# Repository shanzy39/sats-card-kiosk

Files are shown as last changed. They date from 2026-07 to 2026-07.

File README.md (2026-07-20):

# sats-card-kiosk

**Tap a hotel keycard on a little box. Watch Bitcoin appear.**

`sats-card-kiosk` is a DIY, self-contained Lightning kiosk. You lay a repurposed
MIFARE Classic hotel keycard — one that's been loaded with a Bitcoin Lightning
voucher — onto the reader, and the kiosk automatically reads the voucher, claims
it over the internet, and melts the sats into a wallet. A little OLED screen
narrates the whole thing: `tap a card` → `Reading` → `10 sats / claiming...` →
`SUCCESS! melted!`.

No phone, no app, no computer needed at run time. It's an ESP32 microcontroller,
a $7 NFC reader, and a tiny screen — powered by any USB plug — talking to a
self-hosted [LNbits](https://lnbits.com) instance.

This is the redeemer half of a two-part project. Its companion,
[**Sats-Giveaway-Tag-Writer**](https://github.com/shanzy39/Sats-Giveaway-Tag-Writer),
is the *writer* — the browser tool that loads the vouchers onto the cards in the
first place. This repo is the physical machine that claims them back.

---

## What problem does this solve?

A cracked hotel keycard is just a rewritable MIFARE Classic 1K chip. The writer
project turns one into a **bearer card** — it carries a Lightning `LNURL`
withdraw voucher in its memory, like a gift card that holds real value.

But those cards are *closed-loop*: iPhones can't read MIFARE Classic at all, and
neither can many Android phones. So to actually redeem one, **you need a reader
you control.** That's this kiosk. Tap-to-redeem, in a box, that you own.

The result is a fun, physical way to hand out Bitcoin: load a stack of old hotel
cards with small amounts, and let people melt them at the kiosk. Great for demos,
events, and content.

---

## How it works (the flow)

```
   ┌────────────┐     ┌──────────┐     ┌─────────────┐     ┌──────────────┐
   │  Tap card  │ ──▶ │  Read &  │ ──▶ │  Decode the │ ──▶ │  Claim via   │
   │ on reader  │     │  parse   │     │   LNURL     │     │  LNbits over │
   │            │     │  payload │     │  (bech32)   │     │    HTTPS     │
   └────────────┘     └──────────┘     └─────────────┘     └──────────────┘
        NFC              sectors            on-device            WiFi
                         2–15               decode           sats → wallet
```

1. **Read.** The PN532 detects the card and authenticates memory sectors 2–15
   with the factory-default key, reading out the 672-byte payload region.
2. **Parse.** The firmware checks for the `SATS` header the writer wrote
   (`"SATS"` magic + version + type + length) and extracts the voucher string.
3. **Decode.** If it's an `LNURL`, the firmware bech32-decodes it on-device into
   a real `https://…` withdraw URL.
4. **Claim.** Over WiFi + HTTPS: it fetches the withdraw parameters, creates an
   invoice on the kiosk's own LNbits wallet, and submits it to the callback.
   LNbits pays the invoice — the sats move from the voucher's source wallet into
   the kiosk wallet. Because both live on the same LNbits instance, it's an
   instant, feeless internal transfer.
5. **Show.** The OLED reports every step and lands on `SUCCESS! / N sats / melted!`.

Spent, blank, or non-Lightning cards are handled gracefully (`Voucher dead or
used`, `Not a sats card`, etc.) and the kiosk returns to its idle screen.

---

## Bill of materials (~$25)

| Part | Notes |
|---|---|
| **ESP32 dev board** (WROOM-32, 38-pin) | The brain. Built-in WiFi. |
| **PN532 NFC module (V3)** | The reader. Set its DIP switches to **I2C** mode (`1 0`). |
| **SSD1306 0.96" OLED (I2C, 128×64)** | The status screen. Address `0x3C`. |
| Female–female jumper wires | 8 total. No breadboard needed. |
| Micro-USB cable + any 5V USB power | Powers the whole thing. |
| A blank/loaded MIFARE Classic 1K card | The bearer card (e.g. a cracked hotel keycard). |

You also need a running **LNbits** instance (self-hosted or hosted) with a
wallet for the kiosk. See Configuration below.

---

## Wiring

Everything connects directly to the ESP32 with jumper wires — no breadboard.
The PN532 and OLED each get their own I2C bus so they never conflict.

**PN532 → ESP32** (I2C bus `Wire`):

| PN532 | ESP32 |
|---|---|
| GND | GND |
| VCC | 3V3 |
| SDA | GPIO 21 |
| SCL | GPIO 22 |

**OLED → ESP32** (I2C bus `Wire1`):

| OLED | ESP32 |
|---|---|
| GND | GND |
| VCC | VIN (5V) |
| SCL | GPIO 33 |
| SDA | GPIO 32 |

> The PN532 ships with header pins loose — you solder the 4-pin I2C header on.
> Set the PN532's DIP switches to I2C (`1` up / `0` down). The OLED's header is
> usually pre-soldered.

---

## Build & flash

1. **Install the [Arduino IDE](https://www.arduino.cc/en/software).**
2. **Add ESP32 board support.** In *Settings → Additional Boards Manager URLs*, add:
   ```
   https://espressif.github.io/arduino-esp32/package_esp32_index.json
   ```
   Then in *Boards Manager*, install **esp32 by Espressif Systems**. Select board
   **ESP32 Dev Module**.
3. **Install libraries** (*Library Manager*):
   - `Adafruit PN532`
   - `Adafruit SSD1306` (accept its dependencies: Adafruit GFX, BusIO)
4. **Create your config.** Copy `config.example.h` to `config.h` and fill in your
   WiFi and LNbits details (see below). `config.h` is gitignored — your secrets
   never get committed.
5. **Open `kiosk/kiosk.ino`**, select your board's serial port, and click Upload.
6. **Watch it go.** Plug the kiosk into any USB power and tap a card. For debug
   output, open a serial monitor at **115200 baud** (on macOS, the Arduino IDE's
   built-in monitor can be flaky — `screen /dev/cu.usbserial-XXXX 115200` in a
   terminal works well).

### Configuration (`config.h`)

```c
#define WIFI_SSID          "your-wifi-name"        // 2.4GHz only — ESP32 can't do 5GHz
#define WIFI_PASSWORD      "your-wifi-password"
#define LNBITS_HOST        "your-lnbits-domain.com"  // no https://, no trailing slash
#define LNBITS_INVOICE_KEY "your-kiosk-wallet-invoice-key"
```

> **Use a dedicated kiosk wallet.** Create a separate LNbits wallet just for the
> kiosk and use its **invoice/read key** (not the admin key). The invoice key can
> only *create* invoices and read — it can't spend — so even if someone extracted
> the firmware from a kiosk in the wild, they couldn't drain anything.

---

## Repo layout

| Path | What |
|---|---|
| `kiosk/kiosk.ino` | The full firmware — reader + screen + WiFi + LNbits payout. |
| `reader_test/` | Minimal sketch: detect a card and print its UID. First bring-up test. |
| `payload_reader/` | Reads and parses the on-card `SATS` payload (no network). |
| `config.example.h` | Template for your secrets. Copy to `config.h`. |
| `enclosure/` | 3D-printable case — `kiosk_base.stl`, `kiosk_lid.stl`, and the OpenSCAD source. |
| `HANDOFF.md` | Detailed build log / project state (dev reference). |

---

## Enclosure

The `enclosure/` folder has a two-part, print-in-place-free case (base + lid, no
supports). The lid has a window for the OLED, a thin "tap zone" over the reader
(NFC reads right through ~1.5mm of plastic), and a slot for the USB cable. Print
in any color; the top is embossed with **TAP** over the reader and **SATS KIOSK**
along the front. Edit `kiosk_enclosure.scad` if your boards sit differently.

---

## The on-card format

The contract between the writer and this kiosk. The payload lives in MIFARE
Classic sectors 2–15 (data blocks only), all under the default key
`FFFFFFFFFFFF`:

| Offset | Field | |
|---|---|-|
| 0–3 | `"SATS"` | magic bytes |
| 4 | version | `0x01` |
| 5 | type | `0x00` = LNURL, `0x01` = Cashu |
| 6–7 | length | uint16, big-endian |
| 8… | payload | UTF-8 (the `LNURL1…` string) |

v1 firmware supports **LNURL** cards. Cashu is reserved in the format but not yet
melted on-device.

---

## Status & roadmap

**Working end-to-end:** tap → read → decode → claim → sats in wallet, with live
OLED status. Proven on real hardware.

Ideas for later:
- Buzzer + status LEDs for tap feedback
- Custom-key cards (so only *your* kiosk can read them)
- On-device Cashu melting
- A small battery for a fully cordless kiosk

---

## Credits

Built by [shanzy39](https://github.com/shanzy39). Companion to
[Sats-Giveaway-Tag-Writer](https://github.com/shanzy39/Sats-Giveaway-Tag-Writer).
Not affiliated with any hotel or card brand — any MIFARE Classic 1K card works.

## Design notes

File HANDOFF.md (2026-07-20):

# Build Notes — Sats Card Kiosk

_Status: **built & working end-to-end**, assembled in its 3D-printed case. Tap a
bearer card → sats melt into the kiosk's LNbits wallet, with live OLED status._

This is the deeper technical reference and build log. For the overview, wiring,
and step-by-step build guide, start with the [README](README.md). This document
covers the architecture, the on-card format, and the hard-won gotchas — useful if
you're extending the project or debugging your own build.

The companion project that *writes* the cards is
[Sats-Giveaway-Tag-Writer](https://github.com/shanzy39/Sats-Giveaway-Tag-Writer).

---

## Architecture

A tap triggers a five-stage pipeline, all on the ESP32:

1. **Read** — PN532 detects the card, authenticates sectors 2–15 with the default
   key, and reads the 672-byte payload region.
2. **Parse** — verify the `SATS` header and extract the voucher (type + length + bytes).
3. **Decode** — bech32-decode the `LNURL1…` string into an `https://…` withdraw URL.
4. **Claim** — over WiFi/HTTPS:
   - `GET` the withdraw URL → `{callback, k1, maxWithdrawable, …}`
   - `POST /api/v1/payments` on the kiosk wallet (`X-Api-Key: <invoice key>`,
     body `{"out":false,"amount":<sats>,"memo":"kiosk melt"}`) → get a bolt11 invoice
   - `GET callback?k1=<k1>&pr=<bolt11>` → LNbits pays it
5. **Show** — the OLED narrates each stage and lands on `SUCCESS! / N sats / melted!`.

Because the voucher's source wallet and the kiosk wallet live on the same LNbits
instance, the payout is an instant, feeless internal transfer.

Verified end-to-end with a fresh 10-sat voucher:
```
[1/3] Fetching withdraw params...   status 200,  voucher = 10 sats
[2/3] Creating invoice...           status 201,  invoice created
[3/3] Claiming voucher...           status 200,  {"status":"OK"}
*** SUCCESS! 10 sats melted into the kiosk wallet ***
```

## The on-card format

The contract between the writer and this kiosk. Payload lives in MIFARE Classic
1K **sectors 2–15, data blocks 0–2 of each** (blocks `s*4+b` for `s` in 2..15,
`b` in 0..2) = 42 blocks = 672 bytes, all under the default key `FFFFFFFFFFFF`:

| Offset | Field | Notes |
|---|---|---|
| 0–3 | `"SATS"` | magic |
| 4 | version | `0x01` |
| 5 | type | `0x00` = LNURL, `0x01` = Cashu |
| 6–7 | length | uint16, big-endian |
| 8… | payload | UTF-8; the bare uppercase `LNURL1…` string |

The kiosk never touches sector trailers, block 0, or sector 1 (which may hold a
card's original custom-keyed data). v1 firmware melts **LNURL** cards; Cashu is
reserved in the format but not yet melted on-device.

## Pins & wiring

Two independent I2C buses so the reader and screen never conflict — all direct
jumpers, no breadboard.

| Device | Bus | ESP32 pins |
|---|-----|---|
| PN532 (VCC→3V3) | `Wire` | SDA 21, SCL 22 |
| SSD1306 OLED (VCC→VIN/5V) | `Wire1` | SDA 32, SCL 33 |

Firmware essentials: `Wire.begin(21,22)`; `Wire1.begin(32,33)`;
`Adafruit_PN532 nfc(25,26)` (dummy IRQ/RESET — I2C polls fine without them);
`Adafruit_SSD1306 display(128,64,&Wire1,-1)` at address `0x3C`. The PN532's DIP
switches must be set to I2C (`1 0`).

## Bill of materials

| Item | Role |
|---|---|
| ESP32 dev board (WROOM-32) | The brain + WiFi |
| PN532 V3 NFC module | Reader (headers ship unsoldered; solder the 4-pin I2C row) |
| SSD1306 0.96" I2C OLED | Status screen |
| 8× female–female jumpers | Wiring |
| Micro-USB cable + 5V USB power | Power |
| MIFARE Classic 1K card(s) | The bearer cards (e.g. cracked hotel keycards) |
| 3D printer (optional) | For the `enclosure/` case |

Plus a running LNbits instance with a dedicated kiosk wallet. Total electronics
cost ≈ $25.

## Security model

- The kiosk stores only WiFi creds and an LNbits **invoice/read key** — which
  **cannot spend**. It can create invoices and read balances, nothing more. Even
  if a deployed kiosk's firmware were extracted, no funds could be drained.
- Vouchers are single-use, so a card can't be double-claimed.
- Secrets live in `config.h`, which is gitignored. Only `config.example.h`
  (placeholders) is committed.
- **v1 TLS uses `setInsecure()`** (skips cert validation) for simplicity —
  fine on a trusted home network; pin the ISRG Root X1 CA before deploying
  anywhere untrusted. (Tracked in Roadmap.)

## Gotchas (hard-won)

- **Arduino IDE 2.3.10's Serial Monitor can crash the whole IDE to a white screen
  on macOS**, especially around board resets. Reliable alternative: read serial
  from a terminal with `screen /dev/cu.usbserial-XXXX 115200`.
- **`screen` and the uploader both need the port.** Always quit `screen`
  (`Ctrl+A` `K` `Y`) before uploading. A *detached* zombie `screen` session will
  hold the port and produce garbled output — clear it with `screen -ls` then
  `screen -X -S <id> quit`. "Resource busy / could not open port" on upload means
  a session is still attached.
- **ESP32 boot chatter is normal garbage.** The bootloader prints at 74880 baud,
  so the first burst on connect looks like `◊◊◊` at 115200 — ignore it; clean
  text follows.
- **PN532 DIP switches** often ship with a protective film over them and are stiff
  — peel the film, then firmly set to I2C (`1 0`).
- **Hold the card flat and still** for the full read — the kiosk authenticates 14
  sectors in sequence (~2s), and a card that shifts mid-read gives a transient
  `Read failed` before it retries.
- **ESP32 is 2.4GHz-only** — it can't see 5GHz WiFi networks.

## Roadmap

- Buzzer + green/red status LEDs for tap feedback
- Pin the ISRG Root CA (drop `setInsecure()`)
- On-device Cashu melting
- Custom-key cards, so only this kiosk can read them
- Optional battery for a cordless kiosk

## Repo layout

| Path | What |
|---|---|
| `kiosk/kiosk.ino` | Full firmware — reader + OLED + WiFi + LNbits payout |
| `payload_reader/` | Reads & parses the on-card `SATS` payload (no network) |
| `reader_test/` | Minimal card-UID detector — first bring-up test |
| `config.example.h` | Secrets template → copy to `config.h` |
| `enclosure/` | 3D-printable case (STLs + OpenSCAD source) |
| `README.md` | Overview + full build guide |

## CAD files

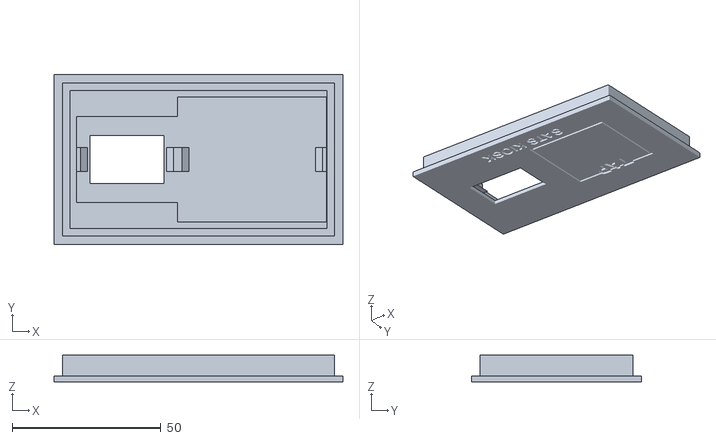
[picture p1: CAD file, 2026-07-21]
enclosure/kiosk_lid_snapfit.stl
97.0 x 57.0 x 9.00

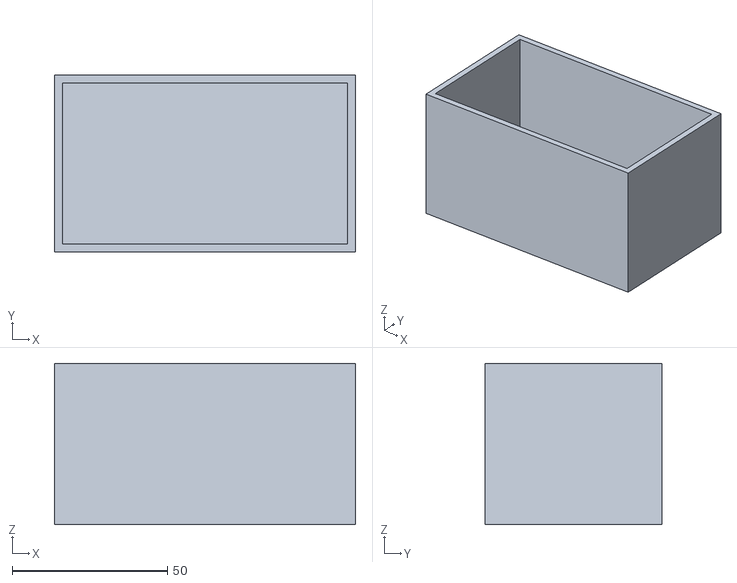
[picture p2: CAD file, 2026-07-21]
enclosure/kiosk_base.stl
97.0 x 57.0 x 52.0

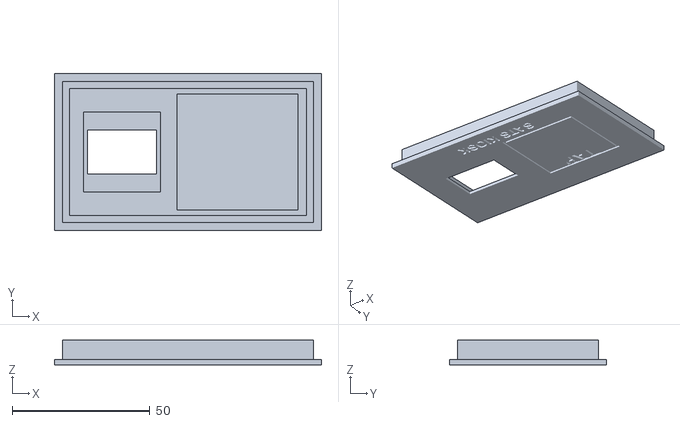
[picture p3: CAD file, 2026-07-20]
enclosure/kiosk_lid.stl
97.0 x 57.0 x 9.00

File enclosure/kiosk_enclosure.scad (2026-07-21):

// Sats Card Kiosk — flat enclosure
// part = "base" or "lid"; rendered separately to two STLs.
// z = 0 is the OUTER top surface of the lid (where a card taps).
part = "base";

/* ---------- parameters ---------- */
wall     = 2.5;   // side wall thickness
floorT   = 2.0;   // base floor thickness
lidTop   = 2.0;   // lid top-plate thickness
tapFloor = 1.6;   // plastic left over the PN532 (card reads through this)
fit      = 0.4;   // clearance for friction fit
$fn      = 48;

// internal cavity (roomy — holds ESP32 + the jumper-wire nest)
inL = 92;
inW = 52;
inH = 50;         // internal depth of the base (deeper for the wire nest)

// board pockets (with clearance)
pnL = 44;  pnW = 42;         // PN532
olL = 28;  olW = 29;         // OLED PCB
olWinL = 25; olWinW = 16;    // OLED screen window (through-hole)

// USB slot (short wall) — generous so the cable reaches regardless of height
usbW = 14; usbZ = 2; usbH = 12;

// derived
extL = inL + 2*wall;
extW = inW + 2*wall;
baseH = floorT + inH;
lipH  = 7;

// window positions along the length
olCX = 22;
pnCX = 64;
cY   = inW/2;

/* ---------- base ---------- */
module base() {
  difference() {
    cube([extL, extW, baseH]);
    translate([wall, wall, floorT]) cube([inL, inW, inH + 1]);   // hollow, open top
    translate([-1, wall + inW/2 - usbW/2, floorT + usbZ])         // USB slot
      cube([wall + 2, usbW, usbH]);
  }
}

/* ---------- lid ---------- */
module lid() {
  difference() {
    union() {
      cube([extL, extW, lidTop]);                                // top plate: z 0..lidTop
      translate([wall + fit, wall + fit, lidTop])                // lip into the base
        difference() {
          cube([inL - 2*fit, inW - 2*fit, lipH]);
          translate([wall, wall, -1])
            cube([inL - 2*fit - 2*wall, inW - 2*fit - 2*wall, lipH + 2]);
        }
    }
    // OLED screen window (through)
    translate([wall + olCX - olWinL/2, wall + cY - olWinW/2, -1])
      cube([olWinL, olWinW, lidTop + 2]);
    // OLED PCB recess from underside (leaves a ~1.2mm ledge the PCB rests on)
    translate([wall + olCX - olL/2, wall + cY - olW/2, lidTop - 0.8])
      cube([olL, olW, 14]);
    // PN532 recess from underside (leaves tapFloor over it)
    translate([wall + pnCX - pnL/2, wall + cY - pnW/2, tapFloor])
      cube([pnL, pnW, 14]);
    // engraved text on the OUTER top face (mirrored in X so it reads correctly
    // when the lid is printed top-face-down and flipped over for use)
    translate([wall + pnCX, wall + cY + 12, -0.1]) mirror([1,0,0])
      linear_extrude(0.9) text("TAP", size=6, halign="center", valign="center", font="Helvetica:style=Bold");
    translate([extL/2, wall + 2.5, -0.1]) mirror([1,0,0])
      linear_extrude(0.9) text("SATS KIOSK", size=4.5, halign="center", valign="baseline", font="Helvetica:style=Bold");
    // engraved card outline over the tap zone
    translate([wall + pnCX, wall + cY - 1, -0.1])
      linear_extrude(0.7)
        difference() {
          square([pnL - 8, pnW - 10], center=true);
          square([pnL - 10, pnW - 12], center=true);
        }
  }
}

if (part == "base") base();
else lid();

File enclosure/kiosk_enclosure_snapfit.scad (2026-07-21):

// Sats Card Kiosk — enclosure v2 (snap-in board retention, no tape)
// part = "base" or "lid".  z = 0 is the OUTER top surface of the lid.
part = "base";

/* ---------- parameters ---------- */
wall     = 2.5;
floorT   = 2.0;
lidTop   = 2.0;
tapFloor = 1.6;    // plastic over the PN532 (card reads through this)
fit      = 0.4;    // lid-into-base friction fit
boardT   = 2.6;    // slot height under the catch — roomy so boards slide fully under
$fn      = 40;

inL = 92; inW = 52; inH = 50;          // internal cavity (deepened for wire nest)

pnL = 44;  pnW = 42;                    // PN532 V3 footprint
olL = 28;  olW = 29;                    // SSD1306 PCB footprint
olWinL = 25; olWinW = 16;              // OLED screen window

// snap-clip geometry  (fingers grip the board's two long edges)
clipW   = 8;       // finger width (along the board edge) — wider grab
clipT   = 1.4;     // finger thickness
clipGap = 1.6;     // clip stand-off from the board edge — clips sit farther apart
clipNub = 2.4;     // nub length (overhang over the board = clipNub - clipGap = 0.8mm)
nubH    = 1.8;     // nub height — taller catch + longer lead-in ramp
fingerH = boardT + 4;   // finger length into the box — taller so the catch reaches

usbW = 14; usbZ = 2; usbH = 12;

extL = inL + 2*wall;  extW = inW + 2*wall;  baseH = floorT + inH;  lipH = 7;
olCX = 22;  pnCX = 64;  cY = inW/2;

/* ---------- base (unchanged — already fits) ---------- */
module base() {
  difference() {
    cube([extL, extW, baseH]);
    translate([wall, wall, floorT]) cube([inL, inW, inH + 1]);
    translate([-1, wall + inW/2 - usbW/2, floorT + usbZ]) cube([wall + 2, usbW, usbH]);
  }
}

/* ---------- board pocket cut ----------
   Widened in X (the clip axis) so the fingers + flex gap fit; the board is
   located tightly in Y by the pocket walls (the header edge is a Y edge, so it
   stays clip-free). */
module pocketCut(cx, cy, bL, bW, seatZ) {
  padX = clipGap + clipT;
  translate([cx - bL/2 - padX, cy - bW/2, seatZ]) cube([bL + 2*padX, bW, 20]);
}

/* ---------- two cantilever snap clips on the board's LEFT & RIGHT (X) edges ----------
   Placed on the side edges so they never touch the pin headers, which sit on a
   Y edge. Each finger hangs from the pocket ceiling into the box and its nub
   overhangs inward over the board's back face. */
module clips(cx, cy, bL, seatZ) {
  backZ = seatZ + boardT;
  for (s = [-1, 1]) {
    xo = cx + s*(bL/2 + clipGap);                  // finger inner face
    // finger post — taller so the catch reaches over a seated board
    translate([s > 0 ? xo : xo - clipT, cy - clipW/2, seatZ])
      cube([clipT, clipW, fingerH]);
    // wedge nub: flat underside at backZ retains the board; sloped top is a
    // lead-in ramp so the board cams the finger outward as you press it in
    if (s > 0)
      hull() {
        translate([xo - clipNub, cy - clipW/2, backZ])       cube([clipNub, clipW, 0.01]);
        translate([xo - 0.01,    cy - clipW/2, backZ + nubH]) cube([0.01,   clipW, 0.01]);
      }
    else
      hull() {
        translate([xo,        cy - clipW/2, backZ])       cube([clipNub, clipW, 0.01]);
        translate([xo,        cy - clipW/2, backZ + nubH]) cube([0.01,   clipW, 0.01]);
      }
  }
}

/* ---------- lid ---------- */
module lid() {
  difference() {
    union() {
      cube([extL, extW, lidTop]);
      translate([wall + fit, wall + fit, lidTop])
        difference() {
          cube([inL - 2*fit, inW - 2*fit, lipH]);
          translate([wall, wall, -1]) cube([inL - 2*fit - 2*wall, inW - 2*fit - 2*wall, lipH + 2]);
        }
    }
    // OLED screen window (through)
    translate([wall + olCX - olWinL/2, wall + cY - olWinW/2, -1]) cube([olWinL, olWinW, lidTop + 2]);
    // board pockets
    pocketCut(wall + olCX, wall + cY, olL, olW, lidTop - 0.5);   // OLED (front on window ledge)
    pocketCut(wall + pnCX, wall + cY, pnL, pnW, tapFloor);        // PN532 (front under tapFloor)
    // engraving on the outer top face (mirrored in X so it reads correctly
    // once the lid is printed top-face-down and flipped over for use)
    translate([wall + pnCX, wall + cY + 13, -0.1]) mirror([1,0,0])
      linear_extrude(0.9) text("TAP", size=6, halign="center", valign="center", font="Helvetica:style=Bold");
    translate([extL/2, wall + 2.5, -0.1]) mirror([1,0,0])
      linear_extrude(0.9) text("SATS KIOSK", size=4.5, halign="center", valign="baseline", font="Helvetica:style=Bold");
    translate([wall + pnCX, wall + cY - 1, -0.1])
      linear_extrude(0.7) difference() { square([pnL-8, pnW-10], center=true); square([pnL-10, pnW-12], center=true); }
  }
  clips(wall + olCX, wall + cY, olL, lidTop - 0.5);   // OLED clips (left/right edges)
  clips(wall + pnCX, wall + cY, pnL, tapFloor);        // PN532 clips (left/right edges)
}

if (part == "base") base();
else lid();

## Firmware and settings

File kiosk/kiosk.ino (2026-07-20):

// Sats Card Kiosk — full firmware (reader + OLED + WiFi + LNbits payout)
// Tap a MIFARE Classic bearer card -> read SATS payload -> decode LNURL ->
// fetch withdraw params -> create invoice on kiosk wallet -> claim -> sats land,
// with live status on a 0.96" SSD1306 OLED.
//
// Hardware (all direct female-female jumpers to the ESP32, no breadboard):
//   PN532 (I2C bus "Wire"):  GND->GND, VCC->3V3, SDA->21, SCL->22
//   OLED  (I2C bus "Wire1"): GND->GND, VCC->VIN(5V), SDA->32, SCL->33   addr 0x3C
// Two independent I2C buses so the devices never share pins.
//
// Needs config.h (gitignored) alongside this file:
//   WIFI_SSID, WIFI_PASSWORD, LNBITS_HOST, LNBITS_INVOICE_KEY
// Libraries: Adafruit PN532, Adafruit SSD1306, Adafruit GFX, Adafruit BusIO.
// Serial @ 115200. v1 uses setInsecure() (skips TLS cert check) — harden later.

#include <WiFi.h>
#include <WiFiClientSecure.h>
#include <HTTPClient.h>
#include <Wire.h>
#include <Adafruit_PN532.h>
#include <Adafruit_GFX.h>
#include <Adafruit_SSD1306.h>
#include "config.h"

Adafruit_PN532 nfc(25, 26);
Adafruit_SSD1306 display(128, 64, &Wire1, -1);
uint8_t defaultKey[6] = {0xFF,0xFF,0xFF,0xFF,0xFF,0xFF};
const char* BECH32_CHARSET = "qpzry9x8gf2tvdw0s3jn54khce6mua7l";

void oled(const String& big, const String& small1="", const String& small2=""){
  display.clearDisplay(); display.setTextColor(SSD1306_WHITE);
  display.setTextSize(2); display.setCursor(0,0); display.println(big);
  display.setTextSize(1);
  if(small1.length()){ display.setCursor(0,28); display.println(small1); }
  if(small2.length()){ display.setCursor(0,44); display.println(small2); }
  display.display();
}
void idle(){
  display.clearDisplay(); display.setTextColor(SSD1306_WHITE);
  display.setTextSize(2);
  display.setCursor(0,0);  display.println("SATS");
  display.setCursor(0,20); display.println("KIOSK");
  display.setTextSize(1); display.setCursor(0,52); display.println("tap a card");
  display.display();
}

int bech32CharValue(char c){ if(c>='A'&&c<='Z')c=c-'A'+'a'; for(int i=0;i<32;i++)if(BECH32_CHARSET[i]==c)return i; return -1; }
int decodeLnurl(const char* lnurl,int lnurlLen,char* out,int outMax){
  int sep=-1; for(int i=0;i<lnurlLen;i++)if(lnurl[i]=='1')sep=i; if(sep<0)return -1;
  int dataStart=sep+1; int dataLen=lnurlLen-dataStart-6; if(dataLen<=0)return -1;
  uint32_t acc=0; int bits=0,outIdx=0;
  for(int i=0;i<dataLen;i++){ int v=bech32CharValue(lnurl[dataStart+i]); if(v<0)return -1;
    acc=(acc<<5)|v; bits+=5; while(bits>=8){bits-=8; if(outIdx>=outMax-1)return -1; out[outIdx++]=(char)((acc>>bits)&0xFF);} }
  out[outIdx]='\0'; return outIdx;
}
String jsonStr(const String& b, const char* k){ String p=String("\"")+k+"\":\""; int i=b.indexOf(p); if(i<0)return ""; i+=p.length(); int j=b.indexOf('"',i); if(j<0)return ""; return b.substring(i,j); }
long jsonNum(const String& b, const char* k){ String p=String("\"")+k+"\":"; int i=b.indexOf(p); if(i<0)return -1; i+=p.length(); int j=i; while(j<(int)b.length()&&b[j]>='0'&&b[j]<='9')j++; return b.substring(i,j).toInt(); }
void connectWiFi(){ if(WiFi.status()==WL_CONNECTED)return; WiFi.begin(WIFI_SSID,WIFI_PASSWORD); int t=0; while(WiFi.status()!=WL_CONNECTED&&t<40){delay(500);t++;} }
String httpsGET(const String& u, int& s){ WiFiClientSecure c; c.setInsecure(); HTTPClient h; String b=""; if(h.begin(c,u)){s=h.GET(); if(s>0)b=h.getString(); h.end();} else s=-999; return b; }
String httpsPOST(const String& u, const String& k, const String& body, int& s){ WiFiClientSecure c; c.setInsecure(); HTTPClient h; String b=""; if(h.begin(c,u)){h.addHeader("Content-Type","application/json"); h.addHeader("X-Api-Key",k); s=h.POST(body); if(s>0)b=h.getString(); h.end();} else s=-999; return b; }

void setup(){
  Serial.begin(115200); delay(1000);
  Wire1.begin(32, 33);
  display.begin(SSD1306_SWITCHCAPVCC, 0x3C);
  oled("SATS","kiosk","connecting wifi...");
  connectWiFi();
  Wire.begin(21, 22); nfc.begin();
  if(!nfc.getFirmwareVersion()){ oled("ERROR","reader not","found"); while(1)delay(1000); }
  nfc.SAMConfig();
  idle();
  Serial.println("Ready.");
}

void loop(){
  uint8_t uid[7],uidLen;
  if(!nfc.readPassiveTargetID(PN532_MIFARE_ISO14443A,uid,&uidLen))return;
  if(uidLen!=4){delay(1500);return;}

  oled("Reading","hold still...");
  uint8_t payload[672]; int idx=0;
  for(uint8_t s=2;s<=15;s++){
    if(!nfc.mifareclassic_AuthenticateBlock(uid,uidLen,s*4,0,defaultKey)){ oled("Re-tap","hold flat"); delay(2000); idle(); return; }
    for(uint8_t b=0;b<3;b++){ if(!nfc.mifareclassic_ReadDataBlock(s*4+b,payload+idx)){ oled("Re-tap","hold flat"); delay(2000); idle(); return; } idx+=16; }
  }
  if(!(payload[0]=='S'&&payload[1]=='A'&&payload[2]=='T'&&payload[3]=='S')){ oled("Not a","sats card"); delay(2500); idle(); return; }
  uint8_t type=payload[5]; uint16_t len=((uint16_t)payload[6]<<8)|payload[7];
  if(len>664||type!=0x00){ oled("Bad card","or Cashu"); delay(2500); idle(); return; }

  char lnurlBuf[680]; for(uint16_t i=0;i<len;i++)lnurlBuf[i]=(char)payload[8+i]; lnurlBuf[len]='\0';
  char url[512]; if(decodeLnurl(lnurlBuf,len,url,sizeof(url))<0){ oled("Decode","failed"); delay(2500); idle(); return; }

  connectWiFi();
  oled("Melting","fetching...");
  int st; String params=httpsGET(String(url),st);
  if(st!=200 || jsonStr(params,"tag")!="withdrawRequest"){ oled("Voucher","dead or","used"); delay(3000); idle(); return; }
  String callback=jsonStr(params,"callback"), k1=jsonStr(params,"k1");
  long sats=jsonNum(params,"maxWithdrawable")/1000;
  if(callback==""||k1==""||sats<=0){ oled("Bad","voucher"); delay(3000); idle(); return; }

  oled(String(sats)+" sats","creating invoice...");
  String invUrl=String("https://")+LNBITS_HOST+"/api/v1/payments";
  String invBody=String("{\"out\":false,\"amount\":")+sats+",\"memo\":\"kiosk melt\"}";
  int st2; String invResp=httpsPOST(invUrl,LNBITS_INVOICE_KEY,invBody,st2);
  String pr=jsonStr(invResp,"payment_request"); if(pr=="")pr=jsonStr(invResp,"bolt11");
  if(pr==""){ oled("Invoice","failed"); delay(3000); idle(); return; }

  oled(String(sats)+" sats","claiming...");
  String claimUrl=callback+"&k1="+k1+"&pr="+pr;
  int st3; String claimResp=httpsGET(claimUrl,st3);
  if(jsonStr(claimResp,"status")=="OK"){
    oled("SUCCESS!",String(sats)+" sats","melted!");
    Serial.printf("SUCCESS %ld sats\n",sats);
  } else { oled("Claim","failed"); Serial.println(claimResp); }
  delay(6000);
  idle();
}

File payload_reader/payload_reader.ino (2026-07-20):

// Sats Card Kiosk — payload reader
// Build day 2 (2026-07-19). Reads the SATS voucher payload out of a bearer card.
// ESP32 + PN532 over I2C (GND->GND, VCC->3V3, SDA->21, SCL->22, no IRQ/RESET wired).
// Auths sectors 2-15 with the default key, reads 672 bytes, parses the SATS header.
// Serial @ 115200. Read output with: screen /dev/cu.usbserial-0001 115200

#include <Wire.h>
#include <Adafruit_PN532.h>

Adafruit_PN532 nfc(25, 26);

uint8_t defaultKey[6] = {0xFF, 0xFF, 0xFF, 0xFF, 0xFF, 0xFF};

void setup() {
  Serial.begin(115200);
  delay(1000);
  Serial.println("\n=== Sats Card Kiosk — payload reader ===");

  Wire.begin(21, 22);
  nfc.begin();

  if (!nfc.getFirmwareVersion()) {
    Serial.println("PN532 not found — check wiring");
    while (1) delay(1000);
  }

  nfc.SAMConfig();
  Serial.println("Tap a bearer card...");
}

void loop() {
  uint8_t uid[7];
  uint8_t uidLen;

  if (!nfc.readPassiveTargetID(PN532_MIFARE_ISO14443A, uid, &uidLen)) return;

  Serial.print("\nCard detected, UID: ");
  for (uint8_t i = 0; i < uidLen; i++) {
    if (uid[i] < 0x10) Serial.print("0");
    Serial.print(uid[i], HEX);
  }
  Serial.println();

  if (uidLen != 4) {
    Serial.println("Not a MIFARE Classic card — can't be a bearer card");
    delay(2000);
    return;
  }

  // Payload region: sectors 2-15, data blocks 0-2 of each = 672 bytes
  uint8_t payload[672];
  int idx = 0;

  for (uint8_t s = 2; s <= 15; s++) {
    if (!nfc.mifareclassic_AuthenticateBlock(uid, uidLen, s * 4, 0, defaultKey)) {
      Serial.print("Auth failed at sector ");
      Serial.println(s);
      Serial.println("(keep the card still and flat, then try again)");
      delay(2000);
      return;
    }
    for (uint8_t b = 0; b < 3; b++) {
      if (!nfc.mifareclassic_ReadDataBlock(s * 4 + b, payload + idx)) {
        Serial.print("Read failed at block ");
        Serial.println(s * 4 + b);
        delay(2000);
        return;
      }
      idx += 16;
    }
  }

  // Parse the SATS header: "SATS" | version | type | length (uint16 BE) | payload
  if (!(payload[0] == 'S' && payload[1] == 'A' && payload[2] == 'T' && payload[3] == 'S')) {
    Serial.println("No SATS payload on this card (blank or hotel data)");
    delay(2000);
    return;
  }

  uint8_t version = payload[4];
  uint8_t type = payload[5];
  uint16_t len = ((uint16_t)payload[6] << 8) | payload[7];

  Serial.print("SATS card! format v");
  Serial.print(version);
  Serial.print(", type: ");
  Serial.print(type == 0x00 ? "LNURL" : type == 0x01 ? "Cashu" : "unknown");
  Serial.print(", length: ");
  Serial.println(len);

  if (len > 664) {
    Serial.println("Length is corrupt — re-tap the card");
    delay(2000);
    return;
  }

  Serial.println("--- Voucher on this card ---");
  for (uint16_t i = 0; i < len; i++) Serial.write(payload[8 + i]);
  Serial.println("\n----------------------------");

  delay(3000);
}

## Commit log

2026-07-20 Sats Card Kiosk — tap a bearer card, sats melt to a wallet
    [kiosk_base.stl, kiosk_enclosure.scad, kiosk_lid.stl]
2026-07-20 Fix mirrored engraving on enclosure lid
    [kiosk_enclosure.scad, kiosk_lid.stl]
2026-07-20 Add snap-fit lid variant; fix mirrored engraving on lids
    [kiosk_enclosure_snapfit.scad, kiosk_lid_snapfit.stl]
2026-07-20 Snap-fit lid: move clips to side edges, two per board, clear of headers
    [kiosk_enclosure_snapfit.scad, kiosk_lid_snapfit.stl]
2026-07-21 Deeper base (inH 34->50mm) for the wire nest; lid unchanged
    [kiosk_base.stl, kiosk_enclosure.scad]
2026-07-21 Snap-fit lid: taller/wider clips with lead-in ramp for easier board insertion
    [kiosk_enclosure_snapfit.scad, kiosk_lid_snapfit.stl]
2026-07-21 Snap-fit lid: wider clip spacing + taller slot so boards seat fully
    [kiosk_enclosure_snapfit.scad, kiosk_lid_snapfit.stl]
